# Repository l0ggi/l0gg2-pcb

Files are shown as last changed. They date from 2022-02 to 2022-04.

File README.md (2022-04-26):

# l0gg2-pcb
2nd gen PCB for l0ggi project

## Project
The idea behind l0ggi is to develop an open source hardware platform to log data, mainly environmental values like temperature and humidity, further also atmospheric pressure, co2, nox etc.
After a quick and dirty pcb with l0gg1 (not working out of the box) the logg2 pcb fixes all bugs of the older iteration and implements the possibility to operate the pcb via battery and accus.
l0gg2 does not feature a usb interface and is designed to be used with the open source tasmota sensors firmware (https://tasmota.github.io/docs/). As the firmware offers the possibility for OTA updates out of the box the usb interface was removed.
The type-c connector of the older iteration is replaced with a overall cheaper micro-usb. The data-lines are not terminated and not used. 

## Ordering
The gerber files are available and proven to work. 
Pick and place files are still in progress

## Firmware
While Tasmota works, the Bosch BME temperature, humidity and atmospheric pressure sensor which is intended to used with the pcb works with Tasmota-Sensors. 

### Flashing
A standard 3.3V FTDI cable can be used, but TX/RX needs to be inverted on the cable. This bug is known and will be fixed in l0gg2.1
Connect USB for power and the adapted FTDI cable to l0gg2. Press PRG (below ESP on the right) and hold and trigger RESET (below ESP on the left). Hold PRG and start flashing via the web tool of tasmota. 

### Configuration (Bosch Sensor, default)
Port | Function
---|---
GPIO0|Button 1
GPIO1|Serial TX
GPIO2|I2C SDA
GPIO3|Serial RX
GPIO4|Button 2
GPIO5|Button 3
GPIO6|
GPIO7|
GPIO8|
GPIO9|
GPIO10|
GPIO11|
GPIO12|
GPIO13|
GPIO14|I2C SCL
GPIO15|
GPIO16|
GPIO17|ADC In

### Configuration (AM2301, soldered to I2C header)
Port | Function
---|---
GPIO0|
GPIO1|
GPIO2|AM2301
GPIO3|
GPIO4|
GPIO5|
GPIO6|
GPIO7|
GPIO8|
GPIO9|
GPIO10|
GPIO11|
GPIO12|
GPIO13|
GPIO14|
GPIO15|
GPIO16|
GPIO17|

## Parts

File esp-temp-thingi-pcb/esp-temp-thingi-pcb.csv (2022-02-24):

Item | Qty | Reference(s) | Value | LibPart | Footprint | Datasheet | Source
1 | 2 | C1, C3 | 10µF | Device:C_Polarized | Capacitor_SMD:CP_Elec_5x5.4 | ~ | https://www.mouser.de/ProductDetail/Cornell-Dubilier-CDE/AVS106M25C12T-F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
2 | 5 | C2, C4, C6, C7, C8 | 100n | Device:C | Capacitor_SMD:C_0603_1608Metric | ~
3 | 1 | C5 | 100µF | Device:C_Polarized | Capacitor_SMD:CP_Elec_5x5.4 | ~
4 | 2 | F1, F2 | 500mA | Device:Fuse | Fuse:Fuse_0805_2012Metric | ~ | https://www.mouser.de/ProductDetail/Bel-Fuse/0ZCK0020FF2G?qs=SRYZG9HaIQ1YaXTwF3oUbw%3D%3D
5 | 2 | J1, J4 | DIO | Connector_Generic:Conn_01x04 | Connector_PinHeader_2.54mm:PinHeader_1x04_P2.54mm_Vertical | ~
6 | 1 | J2 | BAT+ | Connector_Generic:Conn_01x01 | Connector_PinHeader_2.54mm:PinHeader_1x01_P2.54mm_Vertical | ~
7 | 1 | J3 | BAT_GND | Connector_Generic:Conn_01x01 | Connector_PinHeader_2.54mm:PinHeader_1x01_P2.54mm_Vertical | ~
8 | 1 | J5 | I2C | Connector_Generic:Conn_01x04 | Connector_PinHeader_2.54mm:PinHeader_1x04_P2.54mm_Vertical | ~
9 | 1 | J6 | USB_B_Micro | Connector:USB_B_Micro | Connector_USB:USB_Micro-B_Amphenol_10103594-0001LF_Horizontal | ~ | https://www.mouser.de/ProductDetail/Amphenol-FCI/10103594-0001LF
10 | 1 | J7 | FTDI | Connector_Generic:Conn_01x05 | Connector_PinHeader_2.54mm:PinHeader_1x05_P2.54mm_Vertical | ~
11 | 1 | JP1 | Slave_Addr | Jumper:Jumper_3_Bridged12 | Jumper:SolderJumper-3_P1.3mm_Bridged12_Pad1.0x1.5mm | ~
12 | 1 | L1 | 15nH | Device:L | Inductor_SMD:L_0603_1608Metric | ~ | https://www.mouser.de/ProductDetail/Wurth-Elektronik/744786115A?qs=%252BUQ4csG8RsfDfzYws2dmMA%3D%3D
13 | 1 | Q1 | S8050 | Device:Q_NPN_BEC | Package_TO_SOT_SMD:SOT-23 | ~
14 | 6 | R1, R2, R3, R7, R16, R17 | 10k | Device:R | Resistor_SMD:R_0603_1608Metric | ~
15 | 4 | R4, R6, R11, R13 | 100k | Device:R | Resistor_SMD:R_0603_1608Metric | ~
16 | 1 | R5 | 100 | Device:R | Resistor_SMD:R_0603_1608Metric | ~
17 | 1 | R8 | 1k | Device:R | Resistor_SMD:R_0603_1608Metric | ~
18 | 1 | R9 | 0 | Device:R | Resistor_SMD:R_0603_1608Metric | ~
19 | 1 | R10 | N.B. | Device:R | Resistor_SMD:R_0603_1608Metric | ~
20 | 1 | R12 | 20k | Device:R | Resistor_SMD:R_0603_1608Metric | ~
21 | 1 | R14 | 150k | Device:R | Resistor_SMD:R_0603_1608Metric | ~
22 | 1 | R15 | 47k | Device:R | Resistor_SMD:R_0603_1608Metric | ~
23 | 1 | R18 | 1M | Device:R | Resistor_SMD:R_0603_1608Metric | ~
24 | 1 | R19 | 470k | Device:R | Resistor_SMD:R_0603_1608Metric | ~
25 | 2 | R20, R21 | 4k7 | Device:R | Resistor_SMD:R_0603_1608Metric | ~
26 | 1 | SW1 | BTN_2 | Switch:SW_Push | Button_Switch_SMD:Panasonic_EVQPUJ_EVQPUA | ~ | https://www.mouser.de/ProductDetail/Panasonic/EVQ-PUJ02K?qs=Pa1bP%252BeMzadWe338tXJdGA%3D%3D
27 | 1 | SW2 | BTN_1 | Switch:SW_Push | Button_Switch_SMD:Panasonic_EVQPUJ_EVQPUA | ~ | https://www.mouser.de/ProductDetail/Panasonic/EVQ-PUJ02K?qs=Pa1bP%252BeMzadWe338tXJdGA%3D%3D
28 | 1 | SW3 | PRG | Switch:SW_Push | Button_Switch_SMD:Panasonic_EVQPUJ_EVQPUA | ~ | https://www.mouser.de/ProductDetail/Panasonic/EVQ-PUJ02K?qs=Pa1bP%252BeMzadWe338tXJdGA%3D%3D
29 | 1 | SW4 | RESET | Switch:SW_Push | Button_Switch_SMD:Panasonic_EVQPUJ_EVQPUA | ~ | https://www.mouser.de/ProductDetail/Panasonic/EVQ-PUJ02K?qs=Pa1bP%252BeMzadWe338tXJdGA%3D%3D
30 | 1 | U1 | LTC4080 | LTC4080xfa:LTC4080 | footprints:LTC4080EMSE-PBF |  | https://www.mouser.de/ProductDetail/Analog-Devices/LTC4080EMSEPBF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
31 | 1 | U2 | ESP-12E | RF_Module:ESP-12E | RF_Module:ESP-12E | http://wiki.ai-thinker.com/_media/esp8266/esp8266_series_modules_user_manual_v1.1.pdf | https://www.ebay.de/itm/163630302723?hash=item2619204603:g:WjYAAOSwVCpcEAMQ
32 | 1 | U3 | AMS1117-3.3 | Regulator_Linear:AMS1117-3.3 | Package_TO_SOT_SMD:SOT-223-3_TabPin2 | http://www.advanced-monolithic.com/pdf/ds1117.pdf
33 | 1 | U4 | BME280 | Sensor:BME280 | Package_LGA:Bosch_LGA-8_2.5x2.5mm_P0.65mm_ClockwisePinNumbering | https://ae-bst.resource.bosch.com/media/_tech/media/datasheets/BST-BME280-DS002.pdf | https://www.reichelt.de/kombo-sensor-luftdruck-luftfeuchtigkeit-temp--bme-280-p159825.html

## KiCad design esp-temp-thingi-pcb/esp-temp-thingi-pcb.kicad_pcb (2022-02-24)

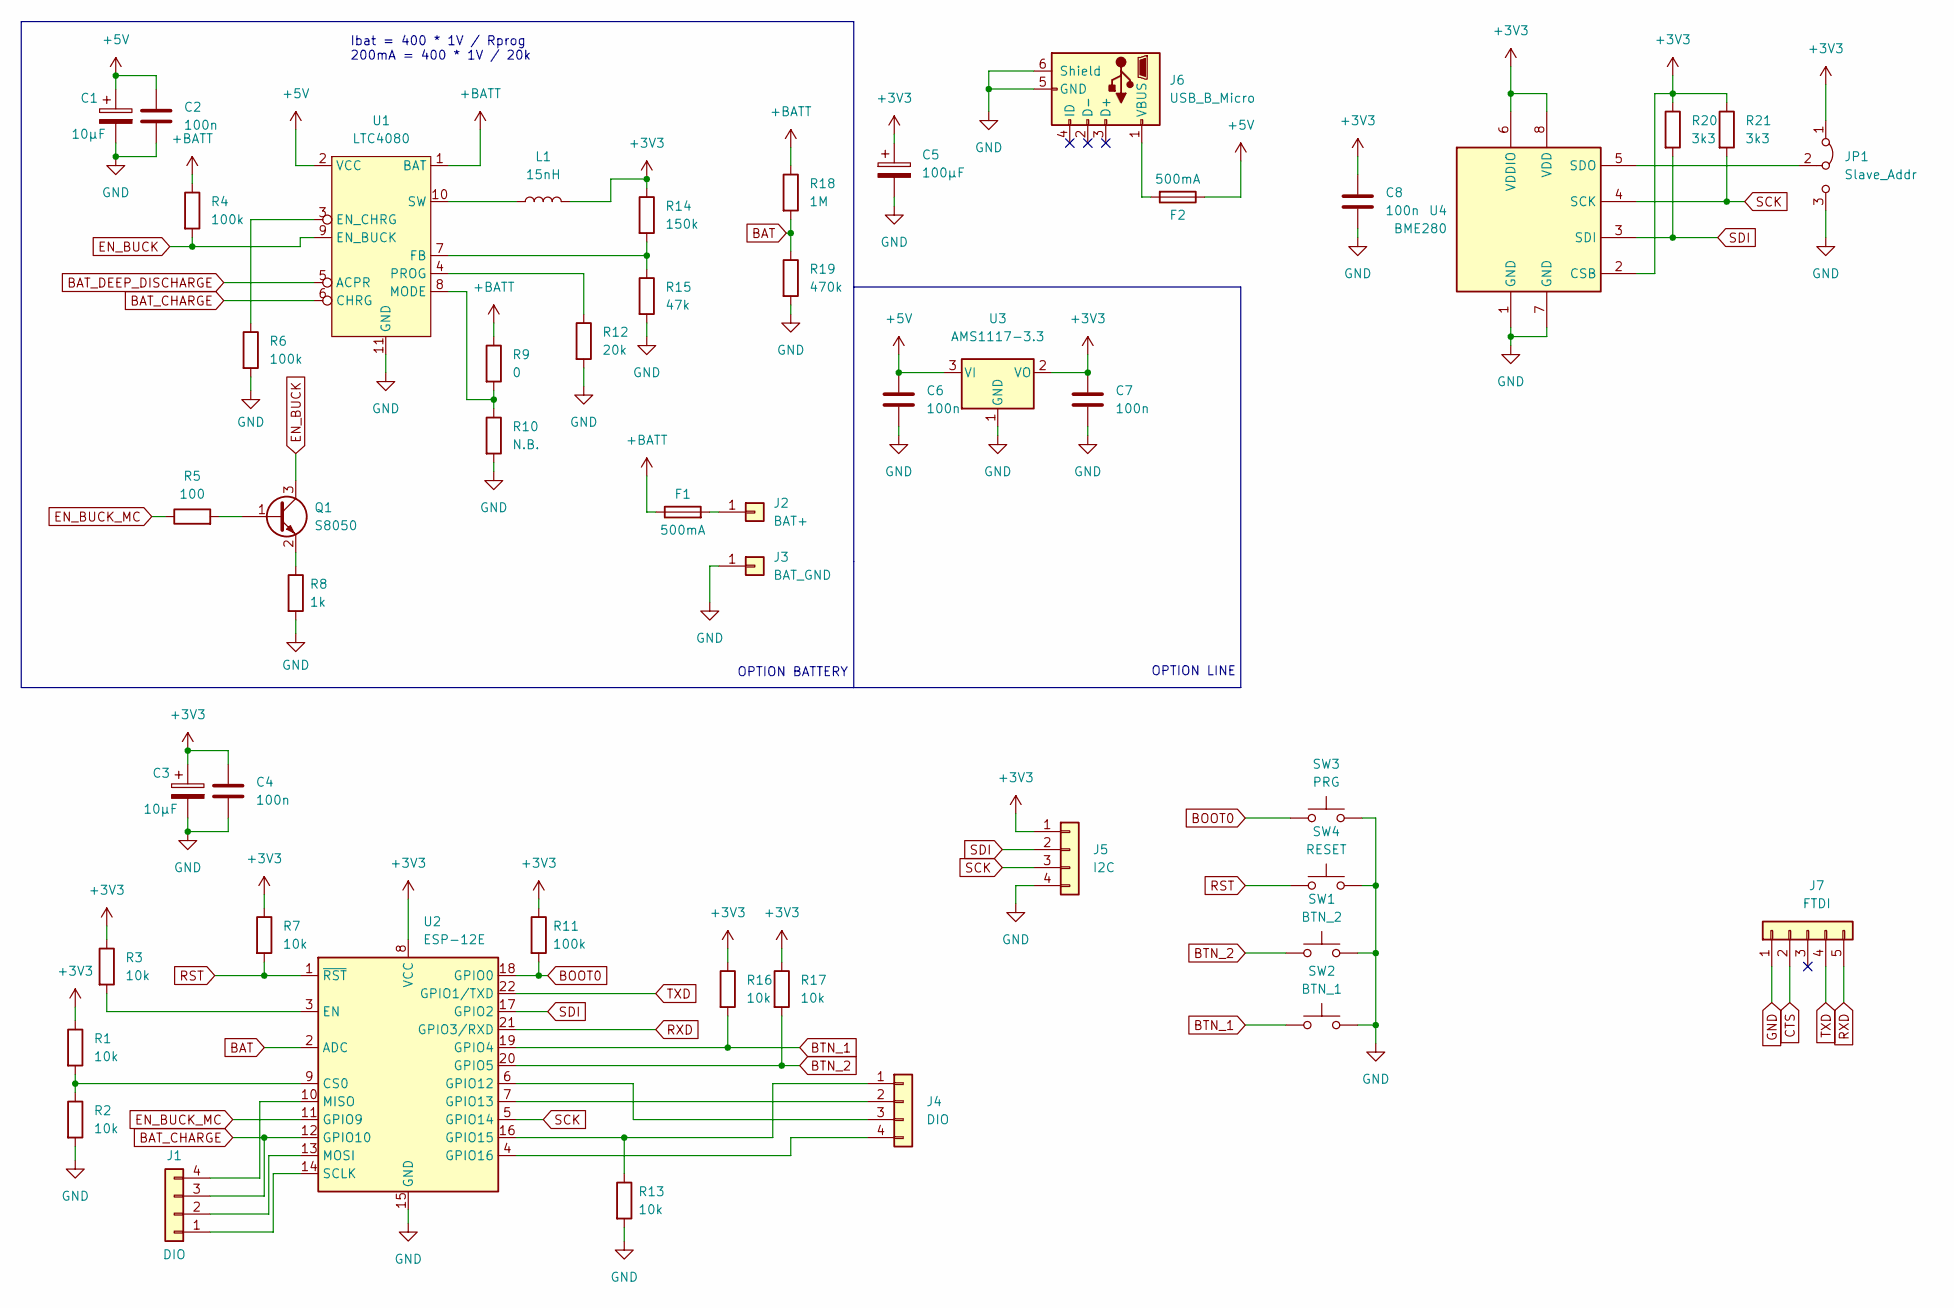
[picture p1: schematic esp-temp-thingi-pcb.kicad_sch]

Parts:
C1, C3: 10µF; CP_Elec_5x5.4
C2, C4, C6, C7, C8: 100n; C_0603_1608Metric
C5: 100µF; CP_Elec_5x5.4
F1, F2: 500mA; Fuse_0805_2012Metric
J1, J4: DIO; PinHeader_1x04_P2.54mm_Vertical
J2: BAT+; PinHeader_1x01_P2.54mm_Vertical
J3: BAT_GND; PinHeader_1x01_P2.54mm_Vertical
J5: I2C; PinHeader_1x04_P2.54mm_Vertical
J6: USB_B_Micro; USB_Micro-B_Amphenol_10103594-0001LF_Horizontal
J7: FTDI; PinHeader_1x05_P2.54mm_Vertical
JP1: Slave_Addr; SolderJumper-3_P1.3mm_Bridged12_Pad1.0x1.5mm
L1: 15nH; L_0603_1608Metric
Q1: S8050; SOT-23
R1, R2, R3, R7, R13, R16, R17: 10k; R_0603_1608Metric
R4, R6, R11: 100k; R_0603_1608Metric
R5: 100; R_0603_1608Metric
R8: 1k; R_0603_1608Metric
R9: 0; R_0603_1608Metric
R10: N.B.; R_0603_1608Metric
R12: 20k; R_0603_1608Metric
R14: 150k; R_0603_1608Metric
R15: 47k; R_0603_1608Metric
R18: 1M; R_0603_1608Metric
R19: 470k; R_0603_1608Metric
R20, R21: 3k3; R_0603_1608Metric
SW1: BTN_2; Panasonic_EVQPUJ_EVQPUA
SW2: BTN_1; Panasonic_EVQPUJ_EVQPUA
SW3: PRG; Panasonic_EVQPUJ_EVQPUA
SW4: RESET; Panasonic_EVQPUJ_EVQPUA
U1: LTC4080; LTC4080EMSE-PBF
U2: ESP-12E
U3: AMS1117-3.3; SOT-223-3_TabPin2
U4: BME280; Bosch_LGA-8_2.5x2.5mm_P0.65mm_ClockwisePinNumbering

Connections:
+3V3: C3.1, C4.1, C5.1, C7.1, C8.1, J5.1, JP1.1 (A), L1.2, R1.1, R3.1, R7.1, R11.1, R14.1, R16.1, R17.1, R20.1, R21.1, U2.8 (VCC), U3.2 (VO), U4.2 (CSB), U4.6 (VDDIO), U4.8 (VDD)
+BATT: F1.1, R4.1, R9.1, R18.1, U1.1 (BAT)
BAT: R18.2, R19.1, U2.2 (ADC)
BAT_CHARGE: J1.3, U1.6 (CHRG), U2.12 (GPIO10)
BAT_DEEP_DISCHARGE: U1.5 (ACPR)
BOOT0: R11.2, SW3.1, U2.18 (GPIO0)
BTN_1: R16.2, SW2.1, U2.19 (GPIO4)
BTN_2: R17.2, SW1.1, U2.20 (GPIO5)
CTS: J7.2
EN_BUCK: Q1.3 (C), R4.2, U1.9 (EN_BUCK)
EN_BUCK_MC: R5.1, U2.11 (GPIO9)
GND: C1.2, C2.2, C3.2, C4.2, C5.2, C6.2, C7.2, C8.2, J3.1, J5.4, J6.5 (GND), J6.6 (Shield), J7.1, JP1.3 (B), R2.2, R8.2, R10.2, R12.2, R13.2, R15.2, R19.2, SW1.2, SW2.2, SW3.2, SW4.2, U1.11 (GND), U2.15 (GND), U3.1 (GND), U4.1 (GND), U4.7 (GND)
unnamed: F1.2, J2.1
unnamed: F2.2, J6.1 (VBUS)
unnamed: J1.1, U2.14 (SCLK)
unnamed: J1.2, U2.13 (MOSI)
unnamed: J1.4, U2.10 (MISO)
unnamed: J4.1, R13.1, U2.16 (GPIO15)
unnamed: J4.2, U2.7 (GPIO13)
unnamed: J4.3, U2.6 (GPIO12)
unnamed: J4.4, U2.4 (GPIO16)
unnamed: JP1.2 (C), U4.5 (SDO)
unnamed: L1.1, U1.10 (SW)
unnamed: Q1.1 (B), R5.2
unnamed: Q1.2 (E), R8.1
unnamed: R1.2, R2.1, U2.9 (CS0)
unnamed: R3.2, U2.3 (EN)
unnamed: R9.2, R10.1, U1.8 (MODE)
unnamed: R12.1, U1.4 (PROG)
unnamed: R14.2, R15.1, U1.7 (FB)
RST: R7.2, SW4.1, U2.1 (~RST)
RXD: J7.5, U2.21 (GPIO3/RXD)
SCK: J5.3, R21.2, U2.5 (GPIO14), U4.4 (SCK)
SDI: J5.2, R20.2, U2.17 (GPIO2), U4.3 (SDI)
TXD: J7.4, U2.22 (GPIO1/TXD)

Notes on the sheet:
OPTION BATTERY
Ibat = 400 * 1V / Rprog 200mA = 400 * 1V / 20k
OPTION LINE

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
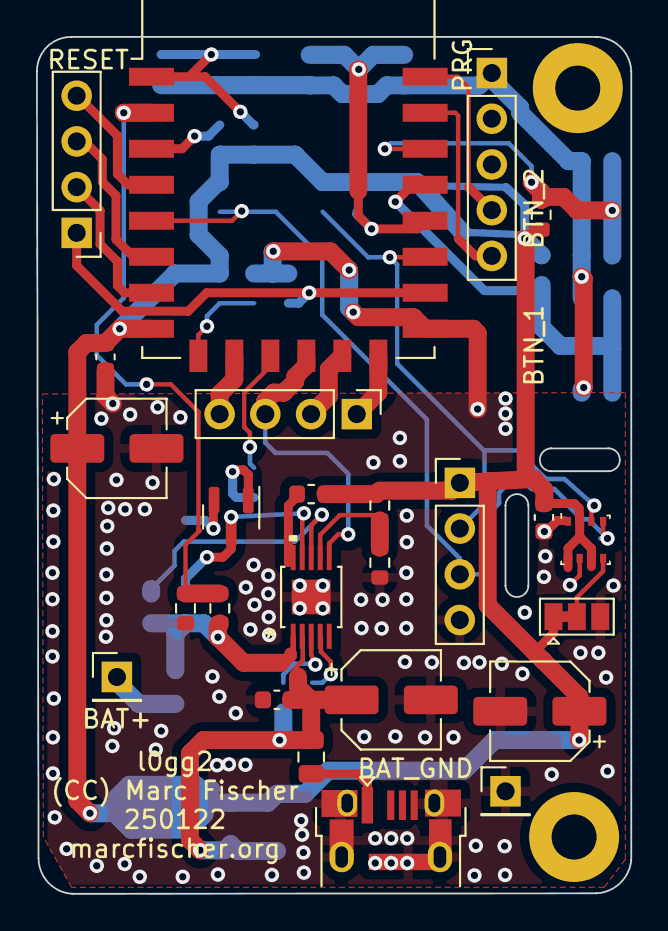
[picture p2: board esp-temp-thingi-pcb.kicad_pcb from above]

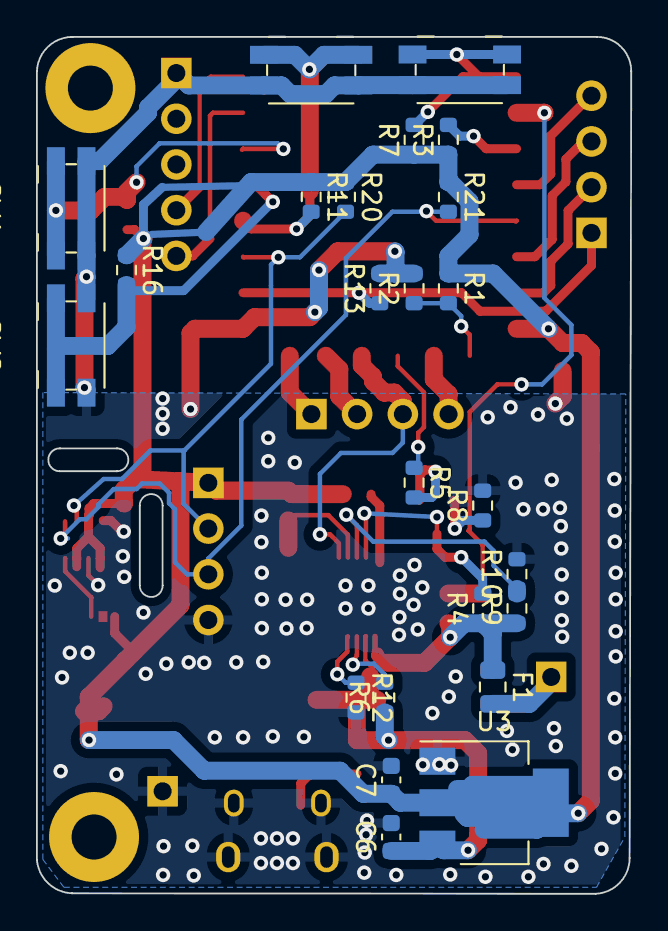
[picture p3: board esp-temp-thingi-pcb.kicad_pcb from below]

Board: 2 copper layers, 33.0 x 47.6 mm, 49 parts (24 on the bottom side), 35 nets.

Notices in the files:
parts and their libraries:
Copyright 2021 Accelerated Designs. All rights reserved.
